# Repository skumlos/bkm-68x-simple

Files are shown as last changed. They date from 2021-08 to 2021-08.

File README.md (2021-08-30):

BKM-68X alternative input board

This project aims to serve as an alternative to the crazy expensive Sony BKM-68X RGB/YPbPr
input card for Sony BVM-A monitors like the BVM-A14F5, A20F1, A24E1W and A32E1W (M/U/A).

The board is rather simple albeit has some components that are not so simple to hand solder,
and it also has a quite high component count (due to a load of resistors and caps).

It's buildup is basically an analog section that deals with video, and a digital section
that speaks to the monitor.

The analog section buffers the video by an THS7374 (with the LPF disabled!) and throws
those through an ADG1611 (or compatible) switch, working via the VIDEO_OE_X signal from
the FPGA. The Y/G signal is first routed through an ISL4089 which strips the sync part 
(if needed) from the signal to avoid too bright picture in YPbPr and SoG signals. This
is however only done if the input is YPbPr at 480p and below and for RGsB signals.
In version 1.1 of the software, this can be switched by turning aperture on. This might
be removed later though, as this is somewhat for testing.

The sync signal is separated through an ISL59885 with a color filter in front (as per
the datasheet), and the signal to be separated (external or Y signal) is chosen via
INT_EXT_X signal to an ADG734 switch.

These are then passed to the FPGA which detects sync polarity and changes accordingly
to positive sync, and then sends the two signals into the monitor.

The digital section consists of a FPGA (Intel MAX 10 in an EQFP-144 package as of this
writing) with a buttload of schmitt triggers and line drivers, all replicated from the
original 68X service manual. The card thus tries to be electrically similar to the
original, at the interface level.

The FPGA is expected to be programmed with the HDL from https://github.com/skumlos/bkm-68x-fpga

75 Ohm termination can be selected by the switches, which either terminates, or passthroughs
(in that case external terminators are needed, unless signal is actually passed through to a
terminating monitor).

The card has no aperture circuit so it can only pass the signal straight through to the monitor
as it originally is (buffered and level conditioned).

Compared to the original BKM-68X, this has severely better sync handling seemingly.

The list of tested consoles that syncs fine as of revision E1 is:

SNES (2CHIP US) 60Hz (CSYNC)

SNES (1CHIP FAT US) 60Hz (CSYNC)

SNES (2CHIP EU) 50Hz (Sync on luma)

SNES (1CHIP EU, SNSP-1CHIP-01) 50Hz (Sync on luma)

Genesis (US) 60Hz (CVBS sync)

Genesis 2 (US) 60Hz (CSYNC)

Mega Drive (EU) 50Hz (CVBS sync)

Mega Drive 2 (EU, DFO) 60Hz (CSYNC)

Mega Drive 2 (EU, DFO) 50Hz (CSYNC)

Master System (on Genesis through Power Base) 60Hz (CVBS sync)

Master System (EU, DFO) 60Hz (CSYNC)

Master System (EU, DFO) 50Hz (CSYNC)

Master System (EU, VA3, no DFO) 60Hz (59,38Hz) (CSYNC)

Master System (EU, VA3, no DFO) 50Hz (CSYNC)

Nintendo 64 (NUSJ) 60Hz (THS7314 RGB) (CSYNC)

Wii (EU) 576i 50Hz (YPbPr)

Wii (EU) 480i 60Hz (YPbPr)

Wii (EU) 480p 60Hz (YPbPr)

PSone SCPH-101 (EU) (MM3+MFO) 60Hz (RGC CSYNC)

PSone SCPH-101 (EU) (MM3+MFO) 50Hz (RGC CSYNC)

PS2 (US) 240p/480i 60Hz (RGBS)

PS2 (US) 480p 60Hz (RGsB)

PS2 (US) 240p/480i/480p (YPbPr)

PS3 (EU) 576i 50Hz (YPbPr)

PS3 (EU) 576p 50Hz (YPbPr)

PS3 (EU) 720p 60Hz (YPbPr)

PS3 (EU) 1080i 60Hz (YPbPr)

PC Engine (White), External RGB mod (THS7374, Genesis 2 plug), 60Hz (CSYNC)

Analogue Nt Mini 2.0 60Hz RGBS (so CSYNC)

Amiga 500 RGBS (PAL) 50Hz (CSYNC)

Xbox 360 (EU) 480i/480p/720p 50/60Hz (YPbPr)

Xbox 360 (EU) 1080i 60Hz (YPbPr) (1080i 50Hz seems to just flicker. Does the same with original 68X)

A load of MiSTer cores which are normally deemed problematic, including DoDonPachi
whose whack VSYNC of 57.6 Hz makes the original BKM-68X scroll the picture with a
steady OSD, while this version has a steady picture with a rolling OSD :)

Master System with CVBS sync works, but sometimes "glitches". This is apparently
due to the quite noisy CVBS signal, which the sync separator picks up. Without
the color filter it is unusable.

It is generally recommended to use CSYNC signals at 75 Ohm levels.

Revision history:

E1: Add "proper" 5V->3.3V translation for sync lines

E: Add "Y/G normalization" control from FPGA

D1: Add STBY_5V pinheader for easier outside-monitor-programming of FPGA.

D: Add DC restore and sync-removal circuit on Y/G line

C1: Minor layout changes

C: Added mounting screw brackets and shortened board for a PCB front, change switch to LFCSP version

B: Added onboard FPGA, color filter, rerouted signals.

A: Initial version

More information @ https://www.immerhax.com

Credits:
Mathias Hyldgaard for providing me with a BVM-A20, which initiated the whole project!
Bob from RetroRGB for testing and listening to my woes :)
The secret benefactor(s) of the original BKM-68X which made the whole project much easier, and ultimately made it possible!
Steve Nutter for being a helpful guy within the pro monitor scene!
The people on the CRT discord and Professional and Broadcast Monitor Facebook group!

(2021) Martin Hejnfelt, martin@hejnfelt.com

This work is released under the CERN Open Hardware Licence version 2 (CERN-OHL-W), see LICENCE.TXT

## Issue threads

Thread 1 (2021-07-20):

Feature Request: Support separate H and V TTL sync inputs

maxtherabbit, 2021-07-20:
This feature would be helpful for the Dreamcast, as well as a myriad of retro computers that output separate sync. Judging by the existing design where all sync sources are separated before being passed along to the monitor, it seems like a fairly trivial feature to accommodate. Amazing work so far!

skumlos, 2021-07-22:
Yes, this should be trivial besides whatever switching mechanism that would also be "needed" and I well definitely put something like this intro this or a future version. I dunno how much it directly helps Dreamcast if the sync from it is whack (as implied by the need of a multivibrator circuit in the vblank period as I understand is present in the RetroAccess cable) but I am gonna look into some of that soon :) and thanks!

maxtherabbit, 2021-07-23:
Well I'm no expert on Dreamcase sync, however I do believe that the use of
the multivibrator in RA's cable is only needed to recreate the serration
pulses during v-blank.

As shown in the attached scope captures, you can see that when natively
outputting separate HV sync, the dreamcast syncs are quite "well-behaved"
with proper h-sync pulses throughout v-blank

On Thu, Jul 22, 2021 at 1:58 PM Martin Hejnfelt ***@***.***>
wrote:

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

maxtherabbit, 2021-07-23:
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

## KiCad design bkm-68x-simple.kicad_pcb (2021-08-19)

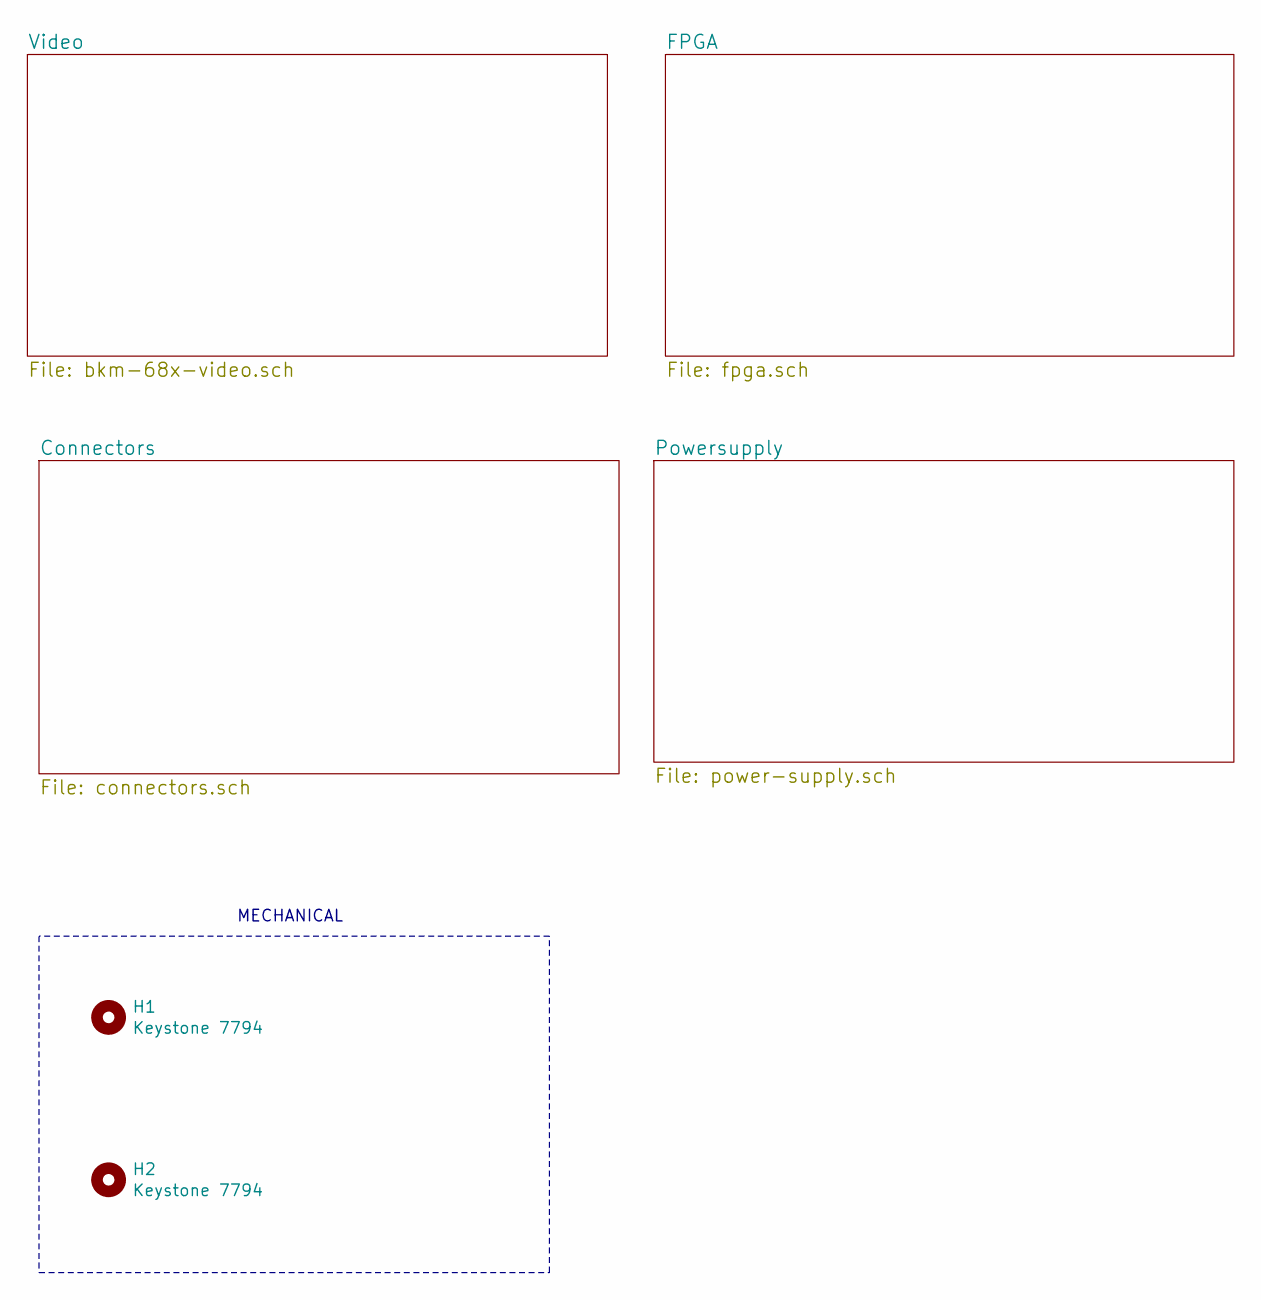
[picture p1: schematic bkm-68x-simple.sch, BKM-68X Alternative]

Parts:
H1, H2: Keystone 7794; 7794-X

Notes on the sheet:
MECHANICAL

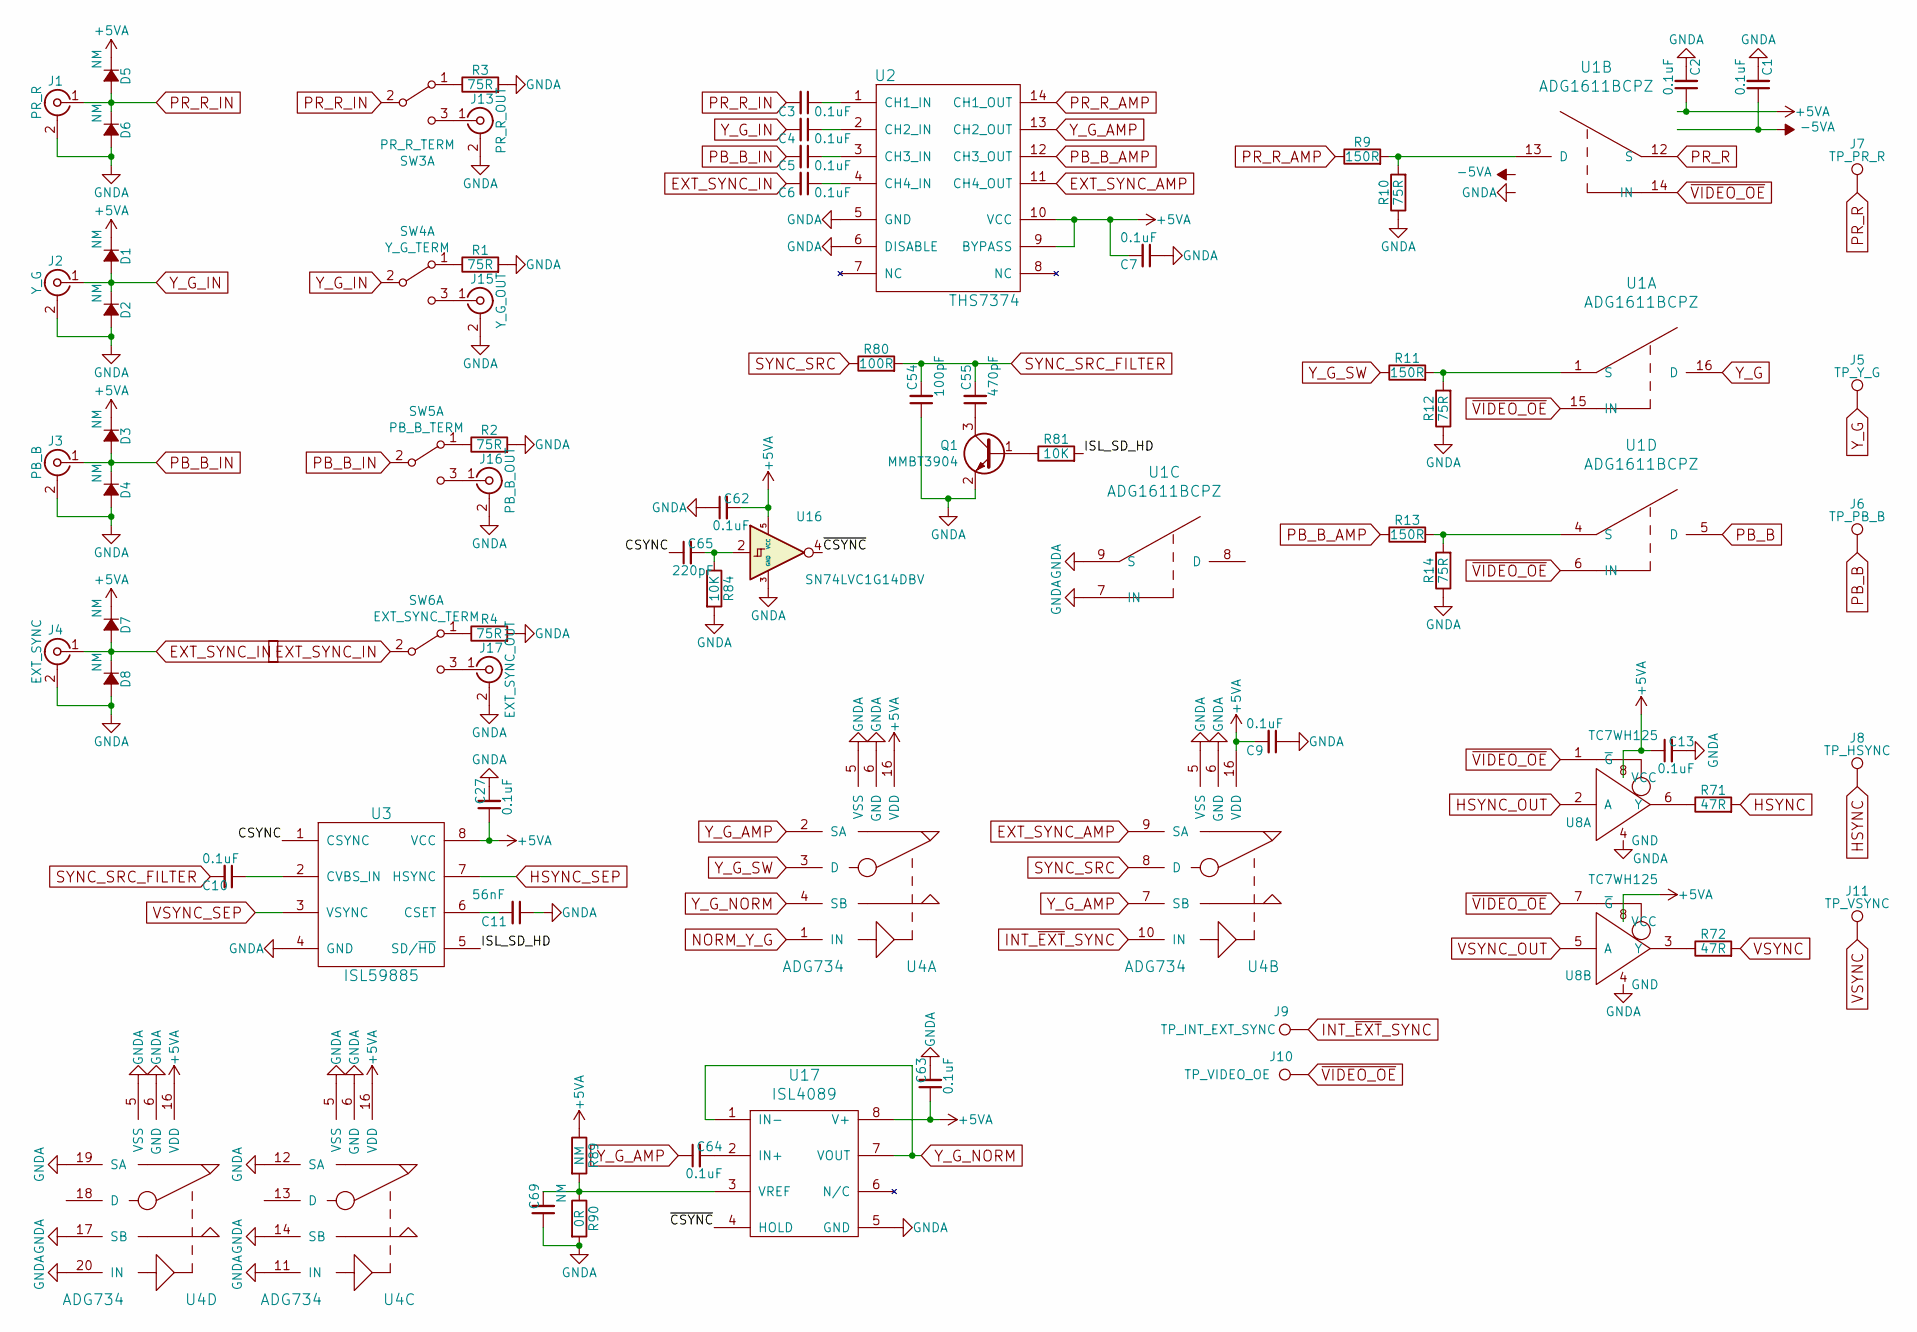
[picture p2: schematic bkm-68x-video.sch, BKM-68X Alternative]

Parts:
C1, C2, C3, C4, C5, C6, C7, C9, C10, C13, C27, C62, C63, C64: 0.1uF; C_0805_2012Metric_Pad1.18x1.45mm_HandSolder
C11: 56nF; C_0805_2012Metric_Pad1.18x1.45mm_HandSolder
C54: 100pF; C_0805_2012Metric_Pad1.18x1.45mm_HandSolder
C55: 470pF; C_0805_2012Metric_Pad1.18x1.45mm_HandSolder
C65: 220pF; C_0805_2012Metric_Pad1.18x1.45mm_HandSolder
C69: NM; C_0805_2012Metric_Pad1.18x1.45mm_HandSolder
D1, D2, D3, D4, D5, D6, D7, D8: NM; D_SOD-123
J1: PR_R; BNC-THT
J2: Y_G; BNC-THT
J3: PB_B; BNC-THT
J4: EXT_SYNC; BNC-THT
J5: TP_Y_G; TestPoint_Pad_D2.0mm
J6: TP_PB_B; TestPoint_Pad_D2.0mm
J7: TP_PR_R; TestPoint_Pad_D2.0mm
J8: TP_HSYNC; TestPoint_Pad_D2.0mm
J9: TP_INT_EXT_SYNC; TestPoint_Pad_D2.0mm
J10: TP_VIDEO_OE; TestPoint_Pad_D2.0mm
J11: TP_VSYNC; TestPoint_Pad_D2.0mm
J13: PR_R_OUT; BNC-THT
J15: Y_G_OUT; BNC-THT
J16: PB_B_OUT; BNC-THT
J17: EXT_SYNC_OUT; BNC-THT
Q1: MMBT3904; SOT-23_Handsoldering
R1, R2, R3, R4, R10, R12, R14: 75R; R_0805_2012Metric_Pad1.20x1.40mm_HandSolder
R9, R11, R13: 150R; R_0805_2012Metric_Pad1.20x1.40mm_HandSolder
R71, R72: 47R; R_0805_2012Metric_Pad1.20x1.40mm_HandSolder
R80: 100R; R_0805_2012Metric_Pad1.20x1.40mm_HandSolder
R81, R84: 10K; R_0805_2012Metric_Pad1.20x1.40mm_HandSolder
R89: NM; R_0805_2012Metric_Pad1.20x1.40mm_HandSolder
R90: 0R; R_0805_2012Metric_Pad1.20x1.40mm_HandSolder
SW3: PR_R_TERM; JS202011SCQN
SW4: Y_G_TERM; JS202011SCQN
SW5: PB_B_TERM; JS202011SCQN
SW6: EXT_SYNC_TERM; JS202011SCQN
U1: ADG1611BCPZ; LFCSP-16-1EP_4x4mm_P0.65mm_EP2.4x2.4mm
U2: THS7374; TSSOP-14_4.4x5mm_P0.65mm
U3: ISL59885; SOIC-8_3.9x4.9mm_P1.27mm
U4: ADG734; TSSOP-20_4.4x6.5mm_P0.65mm
U8: TC7WH125; SSOP-8_2.95x2.8mm_P0.65mm
U16: SN74LVC1G14DBV; SOT-23-5
U17: ISL4089; SOIC-8_3.9x4.9mm_P1.27mm

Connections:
+5VA: C2.1, C7.2, C9.2, C13.1, C27.1, C62.2, C63.1, D1.1 (K), D3.1 (K), D5.1 (K), D7.1 (K), R89.1, U1.11 (VDD), U2.9 (BYPASS), U2.10 (VCC), U3.8 (VCC), U4.16 (VDD), U8.8 (VCC), U16.5 (VCC), U17.8 (V+); also elsewhere on the board
-5VA: C1.1, U1.2 (VSS), U1.17 (EP); also elsewhere on the board
/Video/CSYNC: C65.1, U3.1 (CSYNC)
/Video/ISL_SD_HD: R81.2, U3.5 (SD/~HD)
/Video/~CSYNC: U16.4, U17.4 (HOLD)
EXT_SYNC_AMP: U2.11 (CH4_OUT), U4.9 (SA)
EXT_SYNC_IN: C6.2, D7.2 (A), D8.1 (K), J4.1 (In), SW6.2 (B)
HSYNC: J8.1, R71.2; also elsewhere on the board
HSYNC_OUT: U8.2 (A); also elsewhere on the board
HSYNC_SEP: U3.7 (HSYNC); also elsewhere on the board
INT_~EXT~_SYNC: J9.1, U4.10 (IN); also elsewhere on the board
NORM_Y_G: U4.1 (IN); also elsewhere on the board
unnamed: C3.1, U2.1 (CH1_IN)
unnamed: C4.1, U2.2 (CH2_IN)
unnamed: C5.1, U2.3 (CH3_IN)
unnamed: C6.1, U2.4 (CH4_IN)
unnamed: C10.1, U3.2 (CVBS_IN)
unnamed: C11.2, U3.6 (CSET)
unnamed: C55.1, Q1.3 (C)
unnamed: C64.2, U17.2 (IN+)
unnamed: C65.2, R84.1, U16.2
unnamed: C69.2, R89.2, R90.1, U17.3 (VREF)
unnamed: J13.1 (In), SW3.3 (C)
unnamed: J15.1 (In), SW4.3 (C)
unnamed: J16.1 (In), SW5.3 (C)
unnamed: J17.1 (In), SW6.3 (C)
unnamed: Q1.1 (B), R81.1
unnamed: R1.1, SW4.1 (A)
unnamed: R2.1, SW5.1 (A)
unnamed: R3.1, SW3.1 (A)
unnamed: R4.1, SW6.1 (A)
unnamed: R9.2, R10.2, U1.13 (D)
unnamed: R11.2, R12.2, U1.1 (S)
unnamed: R13.2, R14.2, U1.4 (S)
unnamed: R71.1, U8.6 (Y)
unnamed: R72.1, U8.3 (Y)
PB_B: J6.1, U1.5 (D); also elsewhere on the board
PB_B_AMP: R13.1, U2.12 (CH3_OUT)
PB_B_IN: C5.2, D3.2 (A), D4.1 (K), J3.1 (In), SW5.2 (B)
PR_R: J7.1, U1.12 (S); also elsewhere on the board
PR_R_AMP: R9.1, U2.14 (CH1_OUT)
PR_R_IN: C3.2, D5.2 (A), D6.1 (K), J1.1 (In), SW3.2 (B)
SYNC_SRC: R80.1, U4.8 (D)
SYNC_SRC_FILTER: C10.2, C54.2, C55.2, R80.2
VSYNC: J11.1, R72.2; also elsewhere on the board
VSYNC_OUT: U8.5 (A); also elsewhere on the board
VSYNC_SEP: U3.3 (VSYNC); also elsewhere on the board
Y_G: J5.1, U1.16 (D); also elsewhere on the board
Y_G_AMP: C64.1, U2.13 (CH2_OUT), U4.2 (SA), U4.7 (SB)
Y_G_IN: C4.2, D1.2 (A), D2.1 (K), J2.1 (In), SW4.2 (B)
Y_G_NORM: U4.4 (SB), U17.1 (IN-), U17.7 (VOUT)
Y_G_SW: R11.1, U4.3 (D)
~VIDEO_OE: J10.1, U1.6 (IN), U1.14 (IN), U1.15 (IN), U8.1 (~G), U8.7 (~G); also elsewhere on the board

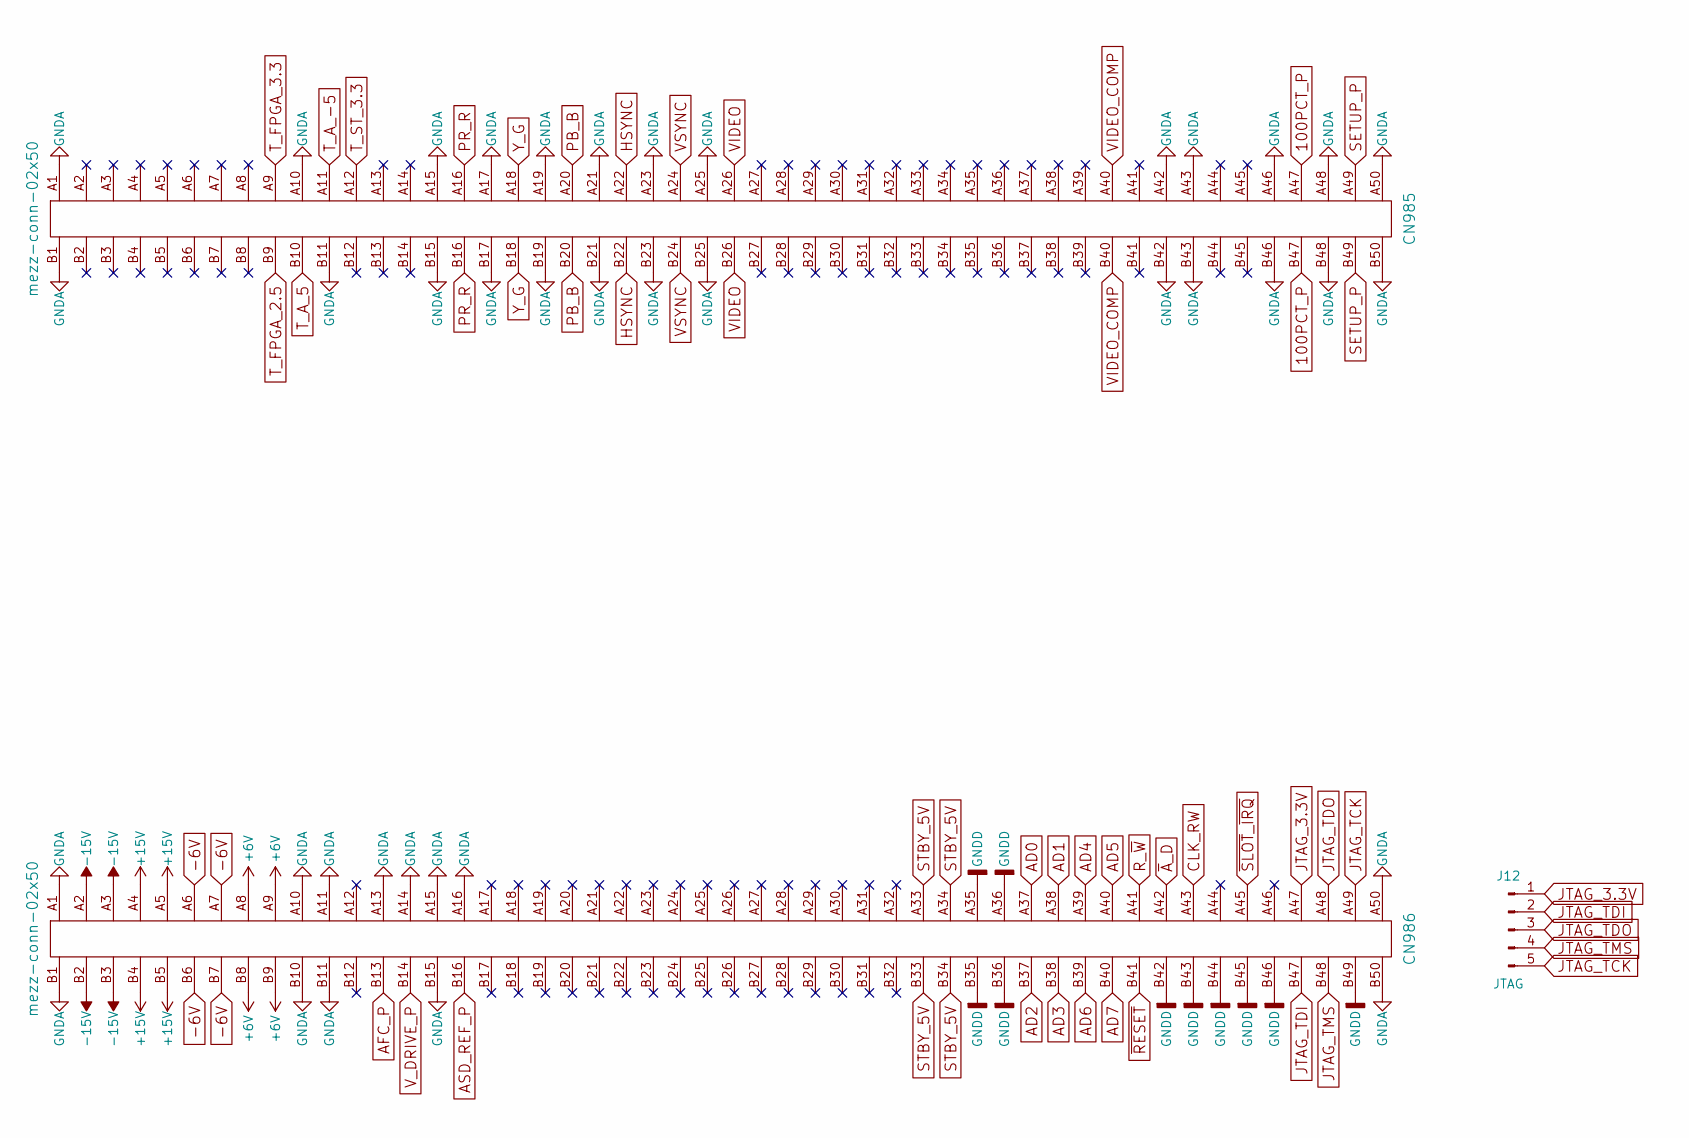
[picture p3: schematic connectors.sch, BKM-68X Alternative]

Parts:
CN985, CN986: mezz-conn-02x50; TX24-100R-LT-H1E
J12: JTAG; PinHeader_1x05_P2.54mm_Vertical

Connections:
100PCT_P: CN985.A47, CN985.B47
+6V: CN986.A8, CN986.A9, CN986.B8, CN986.B9; also elsewhere on the board
+15V: CN986.A4, CN986.A5, CN986.B4, CN986.B5
-6V: CN986.A6, CN986.A7, CN986.B6, CN986.B7; also elsewhere on the board
-15V: CN986.A2, CN986.A3, CN986.B2, CN986.B3
AD0: CN986.A37; also elsewhere on the board
AD1: CN986.A38; also elsewhere on the board
AD2: CN986.B37; also elsewhere on the board
AD3: CN986.B38; also elsewhere on the board
AD4: CN986.A39; also elsewhere on the board
AD5: CN986.A40; also elsewhere on the board
AD6: CN986.B39; also elsewhere on the board
AD7: CN986.B40; also elsewhere on the board
CLK_RW: CN986.A43; also elsewhere on the board
HSYNC: CN985.A22, CN985.B22; also elsewhere on the board
JTAG_3.3V: CN986.A47, J12.1
JTAG_TCK: CN986.A49, J12.5
JTAG_TDI: CN986.B47, J12.2
JTAG_TDO: CN986.A48, J12.3
JTAG_TMS: CN986.B48, J12.4
PB_B: CN985.A20, CN985.B20; also elsewhere on the board
PR_R: CN985.A16, CN985.B16; also elsewhere on the board
R_~W: CN986.A41; also elsewhere on the board
SETUP_P: CN985.A49, CN985.B49
STBY_5V: CN986.A33, CN986.A34, CN986.B33, CN986.B34; also elsewhere on the board
VIDEO: CN985.A26, CN985.B26
VIDEO_COMP: CN985.A40, CN985.B40
VSYNC: CN985.A24, CN985.B24; also elsewhere on the board
Y_G: CN985.A18, CN985.B18; also elsewhere on the board
~A~_D: CN986.A42; also elsewhere on the board
~RESET: CN986.B41; also elsewhere on the board
~SLOT~_~IRQ~: CN986.A45; also elsewhere on the board

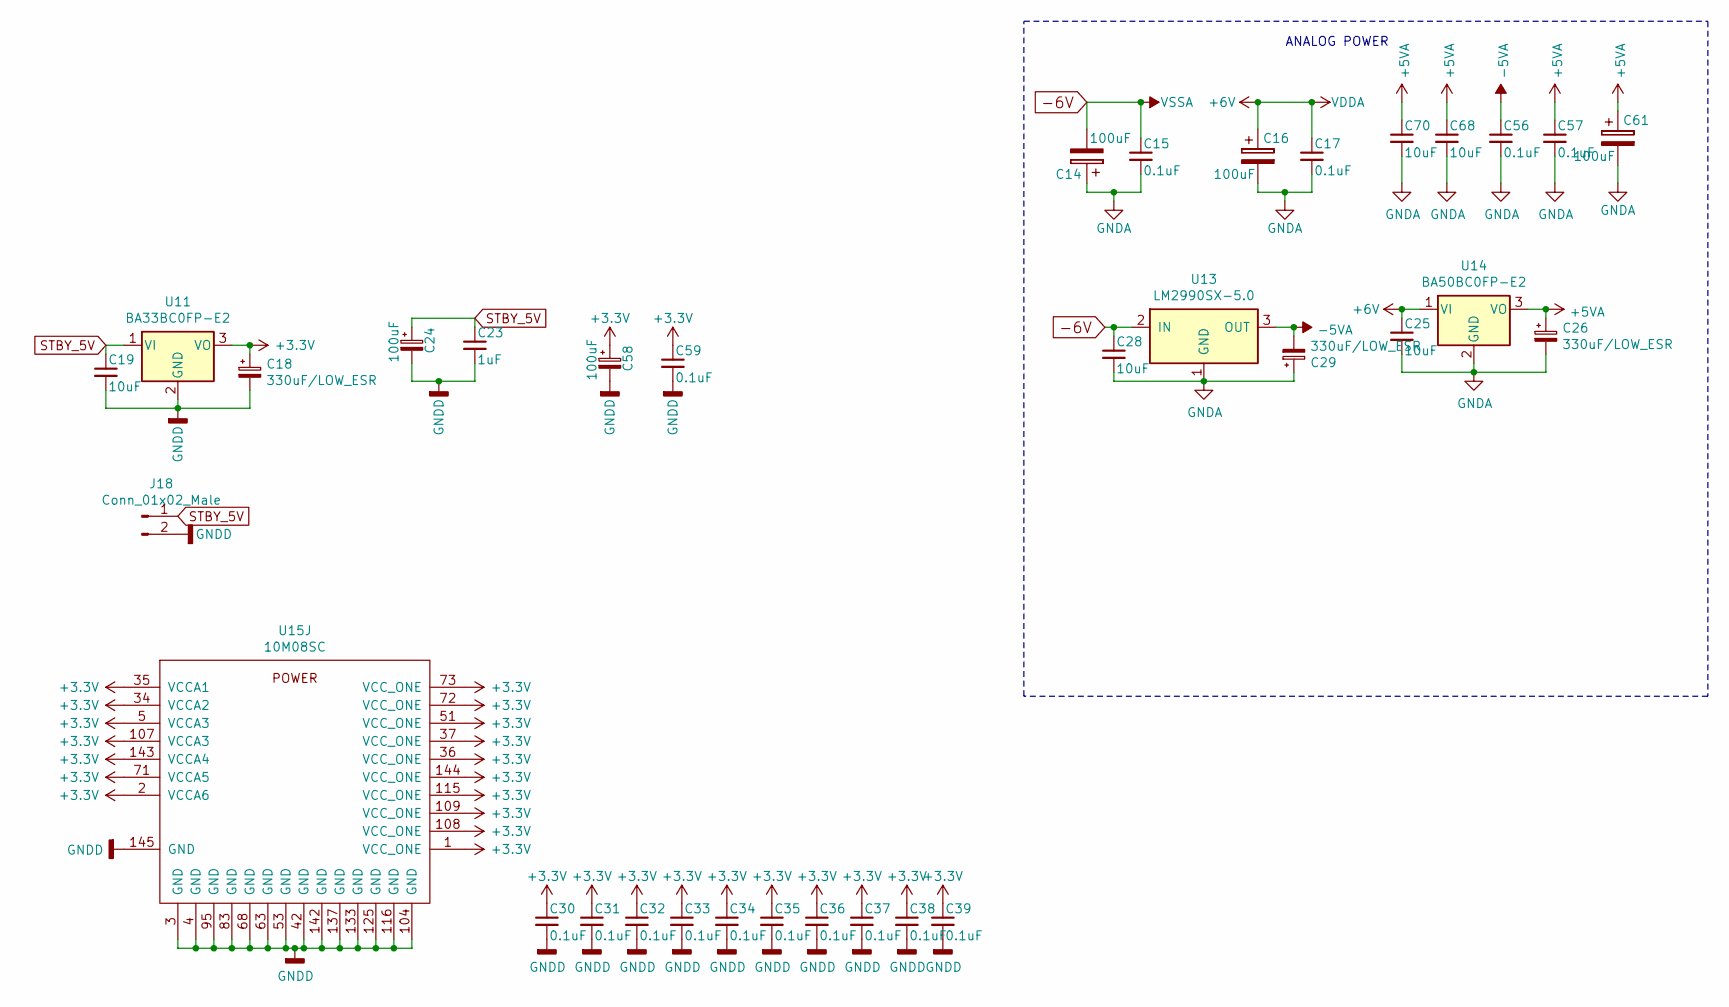
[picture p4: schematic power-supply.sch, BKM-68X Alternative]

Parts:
C14, C16, C61: 100uF; CP_Elec_6.3x5.3
C15, C17, C56, C57, C59: 0.1uF; C_0805_2012Metric_Pad1.18x1.45mm_HandSolder
C18, C26: 330uF/LOW_ESR; CP_Elec_6.3x7.7
C19, C25, C28, C68, C70: 10uF; C_0805_2012Metric_Pad1.18x1.45mm_HandSolder
C23: 1uF; C_0805_2012Metric_Pad1.18x1.45mm_HandSolder
C24, C58: 100uF; CP_Elec_6.3x5.4
C29: 330uF/LOW_ESR; CP_Elec_6.3x5.8
C30, C31, C32, C33, C34, C35, C36, C37, C38, C39: 0.1uF; C_0603_1608Metric_Pad1.08x0.95mm_HandSolder
J18: Conn_01x02_Male; PinHeader_1x02_P2.54mm_Vertical
U11: BA33BC0FP-E2; TO-252-3_TabPin2
U13: LM2990SX-5.0; TO-263-3_TabPin2
U14: BA50BC0FP-E2; TO-252-3_TabPin2
U15: 10M08SC; EQFP-144-1EP_20x20mm_P0.5mm_EP8.93x8.7mm_ThermalVias

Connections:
+3V3: C18.1, C30.1, C31.1, C32.1, C33.1, C34.1, C35.1, C36.1, C37.1, C38.1, C39.1, C58.1, C59.1, U11.3 (VO), U15.1 (VCC_ONE), U15.2 (VCCA6), U15.5 (VCCA3), U15.34 (VCCA2), U15.35 (VCCA1), U15.36 (VCC_ONE), U15.37 (VCC_ONE), U15.51 (VCC_ONE), U15.71 (VCCA5), U15.72 (VCC_ONE), U15.73 (VCC_ONE), U15.107 (VCCA3), U15.108 (VCC_ONE), U15.109 (VCC_ONE), U15.115 (VCC_ONE), U15.143 (VCCA4), U15.144 (VCC_ONE); also elsewhere on the board
+5VA: C26.1, C57.1, C61.1, C68.1, C70.1, U14.3 (VO); also elsewhere on the board
+6V: C16.1, C17.1, C25.1, U14.1 (VI); also elsewhere on the board
-5VA: C29.2, C56.1, U13.3 (OUT); also elsewhere on the board
-6V: C14.2, C15.1, C28.1, U13.2 (IN); also elsewhere on the board
STBY_5V: C19.1, C23.1, C24.1, J18.1, U11.1 (VI); also elsewhere on the board

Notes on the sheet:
ANALOG POWER

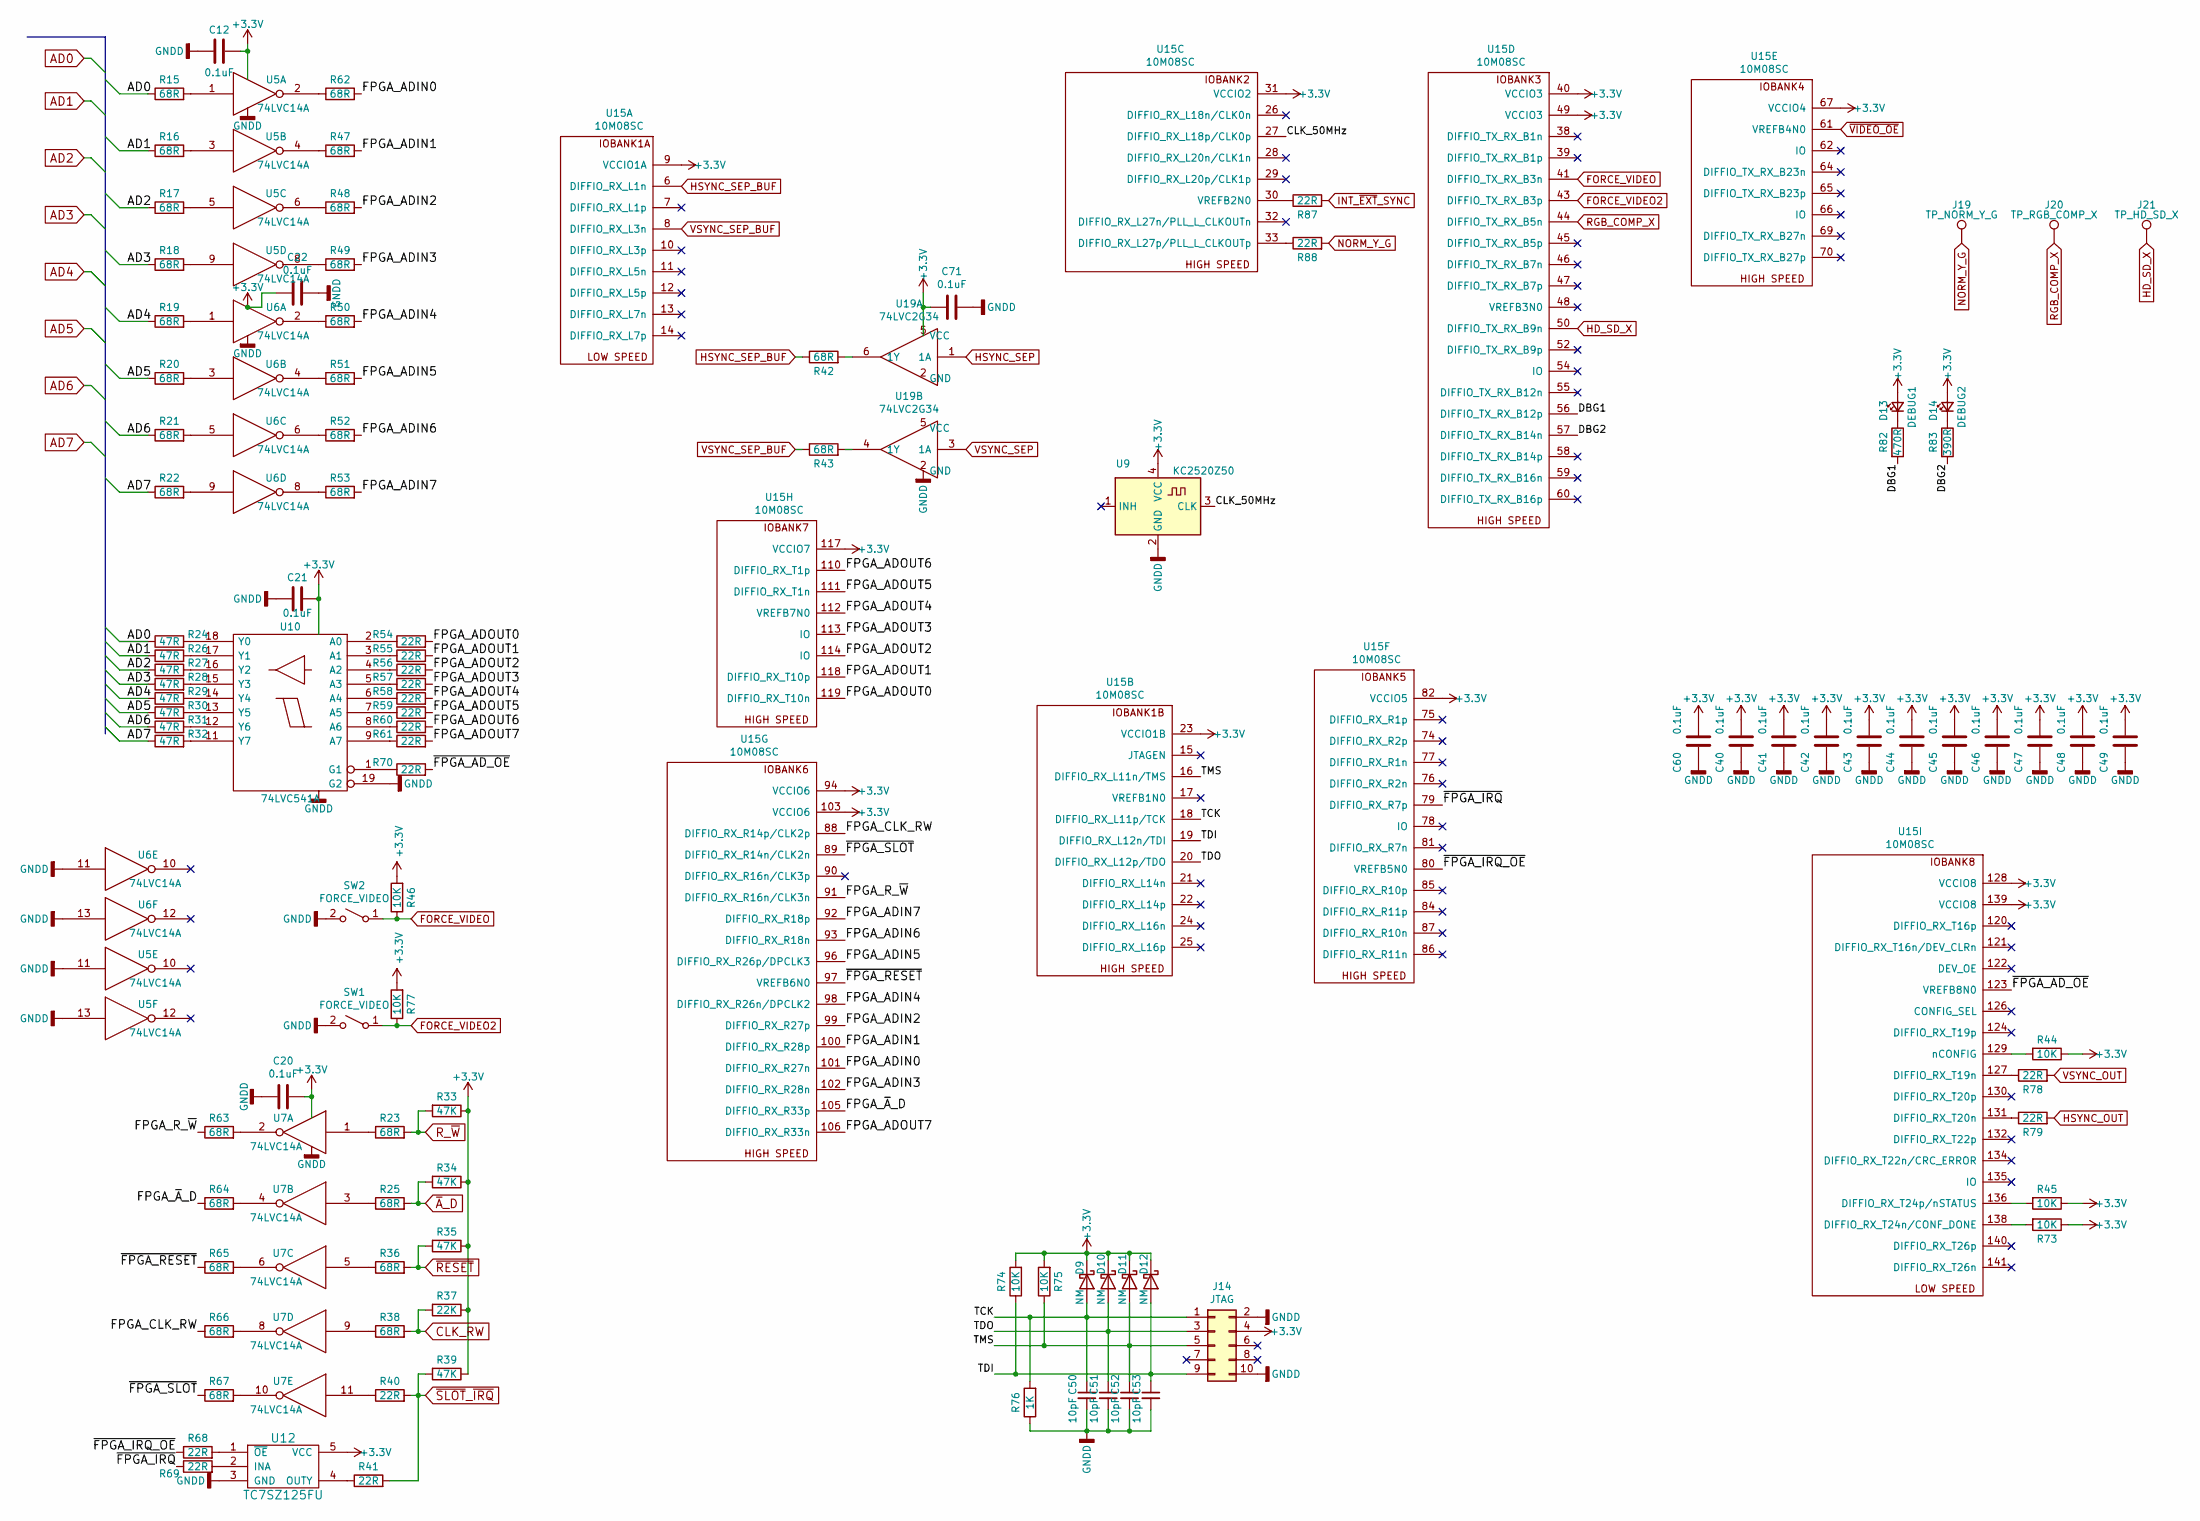
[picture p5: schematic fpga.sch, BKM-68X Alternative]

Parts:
C12, C20, C21, C22, C71: 0.1uF; C_0805_2012Metric_Pad1.18x1.45mm_HandSolder
C40, C41, C42, C43, C44, C45, C46, C47, C48, C49, C60: 0.1uF; C_0603_1608Metric_Pad1.08x0.95mm_HandSolder
C50, C51, C52, C53: 10pF; C_0603_1608Metric_Pad1.08x0.95mm_HandSolder
D9, D10, D11, D12: NM; D_SOD-123
D13: DEBUG1; LED_0805_2012Metric_Pad1.15x1.40mm_HandSolder
D14: DEBUG2; LED_0805_2012Metric_Pad1.15x1.40mm_HandSolder
J14: JTAG; PinHeader_2x05_P2.54mm_Vertical
J19: TP_NORM_Y_G; TestPoint_Pad_D2.0mm
J20: TP_RGB_COMP_X; TestPoint_Pad_D2.0mm
J21: TP_HD_SD_X; TestPoint_Pad_D2.0mm
R15, R16, R17, R18, R19, R20, R21, R22, R23, R25, R36, R38, R42, R43, R47, R48, R49, R50, R51, R52, R53, R62, R63, R64, R65, R66, R67: 68R; R_0805_2012Metric_Pad1.20x1.40mm_HandSolder
R24, R26, R27, R28, R29, R30, R31, R32: 47R; R_0805_2012Metric_Pad1.20x1.40mm_HandSolder
R33, R34, R35, R39: 47K; R_0805_2012Metric_Pad1.20x1.40mm_HandSolder
R37: 22K; R_0805_2012Metric_Pad1.20x1.40mm_HandSolder
R40, R41, R54, R55, R56, R57, R58, R59, R60, R61, R68, R69, R70, R78, R79, R87, R88: 22R; R_0805_2012Metric_Pad1.20x1.40mm_HandSolder
R44, R45, R46, R73, R74, R75, R77: 10K; R_0805_2012Metric_Pad1.20x1.40mm_HandSolder
R76: 1K; R_0805_2012Metric_Pad1.20x1.40mm_HandSolder
R82: 470R; R_0805_2012Metric_Pad1.20x1.40mm_HandSolder
R83: 390R; R_0805_2012Metric_Pad1.20x1.40mm_HandSolder
SW1, SW2: FORCE_VIDEO; PTS645
U5, U6, U7: 74LVC14A; TSSOP-14_4.4x5mm_P0.65mm
U9: KC2520Z50; Oscillator_SMD_Kyocera_KC2520Z-4Pin_2.5x2.0mm
U10: 74LVC541A; TSSOP-20_4.4x6.5mm_P0.65mm
U12: TC7SZ125FU; SOT-353_SC-70-5_Handsoldering
U15: 10M08SC; EQFP-144-1EP_20x20mm_P0.5mm_EP8.93x8.7mm_ThermalVias
U19: 74LVC2G34; SOT-23-6_Handsoldering

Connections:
+3V3: C12.1, C20.1, C21.1, C22.2, C40.1, C41.1, C42.1, C43.1, C44.1, C45.1, C46.1, C47.1, C48.1, C49.1, C60.1, C71.2, D9.1 (K), D10.1 (K), D11.1 (K), D12.1 (K), D13.2 (A), D14.2 (A), J14.4, R33.1, R34.1, R35.1, R37.1, R39.1, R44.1, R45.1, R46.2, R73.1, R74.2, R75.2, R77.2, U5.14 (VCC), U6.14 (VCC), U7.14 (VCC), U9.4 (VCC), U10.20 (VCC), U12.5 (VCC), U15.9 (VCCIO1A), U15.23 (VCCIO1B), U15.31 (VCCIO2), U15.40 (VCCIO3), U15.49 (VCCIO3), U15.67 (VCCIO4), U15.82 (VCCIO5), U15.94 (VCCIO6), U15.103 (VCCIO6), U15.117 (VCCIO7), U15.128 (VCCIO8), U15.139 (VCCIO8), U19.5 (VCC); also elsewhere on the board
/FPGA/CLK_50MHz: U9.3 (CLK), U15.27 (DIFFIO_RX_L18p/CLK0p)
/FPGA/DBG1: R82.2, U15.56 (DIFFIO_TX_RX_B12p)
/FPGA/DBG2: R83.2, U15.57 (DIFFIO_TX_RX_B14n)
/FPGA/FPGA_ADIN0: R62.2, U15.101 (DIFFIO_RX_R27n)
/FPGA/FPGA_ADIN1: R47.2, U15.100 (DIFFIO_RX_R28p)
/FPGA/FPGA_ADIN2: R48.2, U15.99 (DIFFIO_RX_R27p)
/FPGA/FPGA_ADIN3: R49.2, U15.102 (DIFFIO_RX_R28n)
/FPGA/FPGA_ADIN4: R50.2, U15.98 (DIFFIO_RX_R26n/DPCLK2)
/FPGA/FPGA_ADIN5: R51.2, U15.96 (DIFFIO_RX_R26p/DPCLK3)
/FPGA/FPGA_ADIN6: R52.2, U15.93 (DIFFIO_RX_R18n)
/FPGA/FPGA_ADIN7: R53.2, U15.92 (DIFFIO_RX_R18p)
/FPGA/FPGA_ADOUT0: R54.2, U15.119 (DIFFIO_RX_T10n)
/FPGA/FPGA_ADOUT1: R55.2, U15.118 (DIFFIO_RX_T10p)
/FPGA/FPGA_ADOUT2: R56.2, U15.114 (IO)
/FPGA/FPGA_ADOUT3: R57.2, U15.113 (IO)
/FPGA/FPGA_ADOUT4: R58.2, U15.112 (VREFB7N0)
/FPGA/FPGA_ADOUT5: R59.2, U15.111 (DIFFIO_RX_T1n)
/FPGA/FPGA_ADOUT6: R60.2, U15.110 (DIFFIO_RX_T1p)
/FPGA/FPGA_ADOUT7: R61.2, U15.106 (DIFFIO_RX_R33n)
/FPGA/FPGA_CLK_RW: R66.1, U15.88 (DIFFIO_RX_R14p/CLK2p)
/FPGA/FPGA_R_~W: R63.1, U15.91 (DIFFIO_RX_R16n/CLK3n)
/FPGA/FPGA_~A~_D: R64.1, U15.105 (DIFFIO_RX_R33p)
/FPGA/TCK: C50.1, D9.2 (A), J14.1, R76.2, U15.18 (DIFFIO_RX_L11p/TCK)
/FPGA/TDI: C53.1, D12.2 (A), J14.9, R74.1, U15.19 (DIFFIO_RX_L12n/TDI)
/FPGA/TDO: C51.1, D10.2 (A), J14.3, U15.20 (DIFFIO_RX_L12p/TDO)
/FPGA/TMS: C52.1, D11.2 (A), J14.5, R75.1, U15.16 (DIFFIO_RX_L11n/TMS)
/FPGA/~FPGA_AD_OE: R70.2, U15.123 (VREFB8N0)
/FPGA/~FPGA_IRQ: R69.1, U15.79 (DIFFIO_RX_R7p)
/FPGA/~FPGA_IRQ_OE: R68.1, U15.80 (VREFB5N0)
/FPGA/~FPGA_RESET: R65.1, U15.97 (VREFB6N0)
/FPGA/~FPGA_SLOT: R67.1, U15.89 (DIFFIO_RX_R14n/CLK2n)
AD0: R15.1, R24.1; also elsewhere on the board
AD1: R16.1, R26.1; also elsewhere on the board
AD2: R17.1, R27.1; also elsewhere on the board
AD3: R18.1, R28.1; also elsewhere on the board
AD4: R19.1, R29.1; also elsewhere on the board
AD5: R20.1, R30.1; also elsewhere on the board
AD6: R21.1, R31.1; also elsewhere on the board
AD7: R22.1, R32.1; also elsewhere on the board
CLK_RW: R37.2, R38.2; also elsewhere on the board
FORCE_VIDEO: R46.1, SW2.1 (A), U15.41 (DIFFIO_TX_RX_B3n)
FORCE_VIDEO2: R77.1, SW1.1 (A), U15.43 (DIFFIO_TX_RX_B3p)
HD_SD_X: J21.1, U15.50 (DIFFIO_TX_RX_B9n)
HSYNC_OUT: R79.2; also elsewhere on the board
HSYNC_SEP: U19.1 (1A); also elsewhere on the board
HSYNC_SEP_BUF: R42.1, U15.6 (DIFFIO_RX_L1n)
INT_~EXT~_SYNC: R87.2; also elsewhere on the board
NORM_Y_G: J19.1, R88.2; also elsewhere on the board
unnamed: D13.1 (K), R82.1
unnamed: D14.1 (K), R83.1
unnamed: R15.2, U5.1
unnamed: R16.2, U5.3
unnamed: R17.2, U5.5
unnamed: R18.2, U5.9
unnamed: R19.2, U6.1
unnamed: R20.2, U6.3
unnamed: R21.2, U6.5
unnamed: R22.2, U6.9
unnamed: R23.1, U7.1
unnamed: R24.2, U10.18 (Y0)
unnamed: R25.1, U7.3
unnamed: R26.2, U10.17 (Y1)
unnamed: R27.2, U10.16 (Y2)
unnamed: R28.2, U10.15 (Y3)
unnamed: R29.2, U10.14 (Y4)
unnamed: R30.2, U10.13 (Y5)
unnamed: R31.2, U10.12 (Y6)
unnamed: R32.2, U10.11 (Y7)
unnamed: R36.1, U7.5
unnamed: R38.1, U7.9
unnamed: R40.1, U7.11
unnamed: R41.1, U12.4 (OUTY)
unnamed: R42.2, U19.6 (1Y)
unnamed: R43.2, U19.4 (1Y)
unnamed: R44.2, U15.129 (nCONFIG)
unnamed: R45.2, U15.136 (DIFFIO_RX_T24p/nSTATUS)
unnamed: R47.1, U5.4
unnamed: R48.1, U5.6
unnamed: R49.1, U5.8
unnamed: R50.1, U6.2
unnamed: R51.1, U6.4
unnamed: R52.1, U6.6
unnamed: R53.1, U6.8
unnamed: R54.1, U10.2 (A0)
unnamed: R55.1, U10.3 (A1)
unnamed: R56.1, U10.4 (A2)
unnamed: R57.1, U10.5 (A3)
unnamed: R58.1, U10.6 (A4)
unnamed: R59.1, U10.7 (A5)
unnamed: R60.1, U10.8 (A6)
unnamed: R61.1, U10.9 (A7)
unnamed: R62.1, U5.2
unnamed: R63.2, U7.2
unnamed: R64.2, U7.4
unnamed: R65.2, U7.6
unnamed: R66.2, U7.8
unnamed: R67.2, U7.10
unnamed: R68.2, U12.1 (~OE)
unnamed: R69.2, U12.2 (INA)
unnamed: R70.1, U10.1 (G1)
unnamed: R73.2, U15.138 (DIFFIO_RX_T24n/CONF_DONE)
unnamed: R78.1, U15.127 (DIFFIO_RX_T19n)
unnamed: R79.1, U15.131 (DIFFIO_RX_T20n)
unnamed: R87.1, U15.30 (VREFB2N0)
unnamed: R88.1, U15.33 (DIFFIO_RX_L27p/PLL_L_CLKOUTp)
RGB_COMP_X: J20.1, U15.44 (DIFFIO_TX_RX_B5n)
R_~W: R23.2, R33.2; also elsewhere on the board
VSYNC_OUT: R78.2; also elsewhere on the board
VSYNC_SEP: U19.3 (1A); also elsewhere on the board
VSYNC_SEP_BUF: R43.1, U15.8 (DIFFIO_RX_L3n)
~A~_D: R25.2, R34.2; also elsewhere on the board
~RESET: R35.2, R36.2; also elsewhere on the board
~SLOT~_~IRQ~: R39.2, R40.2, R41.2; also elsewhere on the board
~VIDEO_OE: U15.61 (VREFB4N0); also elsewhere on the board

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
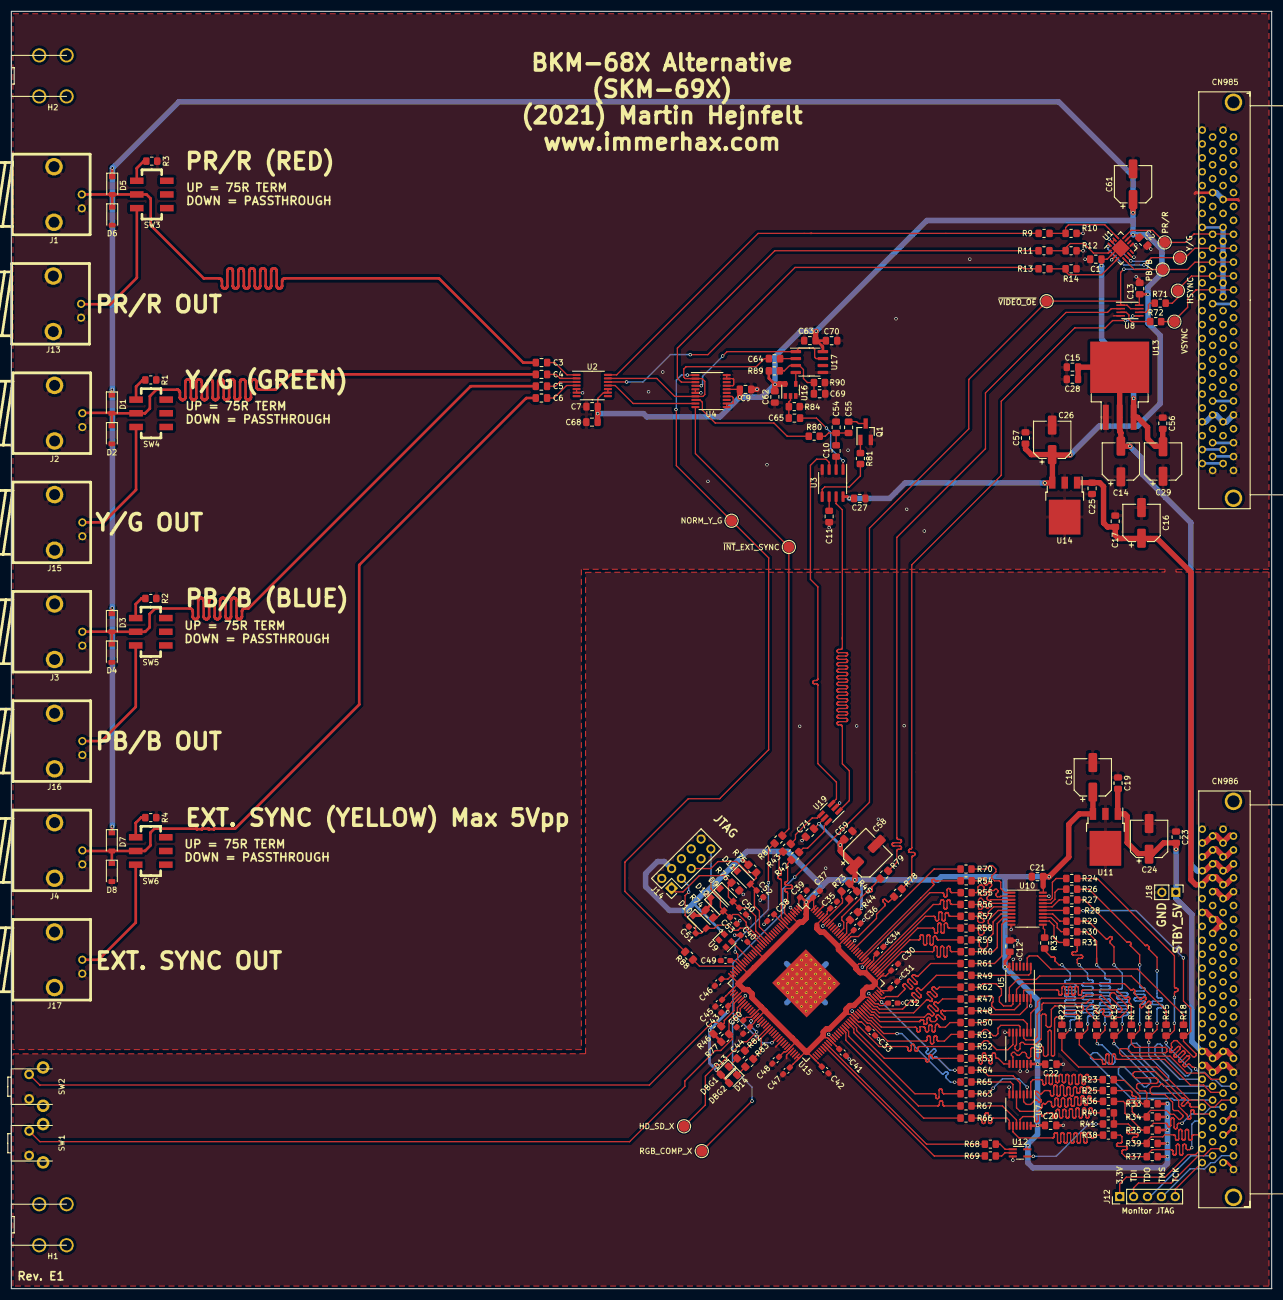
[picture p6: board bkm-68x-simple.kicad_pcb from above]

Board: 2 copper layers, 230.4 x 233.5 mm, 216 parts (0 on the bottom side), 176 nets.

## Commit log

2021-03-21 Minor fixes and cleanups
    [bkm-68x-simple.kicad_pcb, power-supply.sch]
2021-04-18 A lotta fixes
    [bkm-68x-simple.kicad_pcb, bkm-68x-video.sch, fpga.sch]
2021-05-14 Onboard FPGA, passthroughs and a lot of other stuff
    [bkm-68x-simple.kicad_pcb, bkm-68x-video.sch, fpga.sch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]
2021-05-16 Updated some component values
    [bkm-68x-simple.kicad_pcb, bkm-68x-video.sch, fpga.sch]
2021-05-16 Fixes and additions
    [bkm-68x-simple.kicad_pcb, bkm-68x-simple.sch, fpga.sch]
2021-05-17 Shortened board slightly for PCB front, rev C
    [bkm-68x-simple.kicad_pcb]
2021-05-25 Replace ADG1611BRUZ with BCPZ
    Should also be compatible with Vishay DG1411EEN-T1-GE4
    [bkm-68x-simple.kicad_pcb, bkm-68x-video.sch, power-supply.sch]
2021-06-01 Rev C1
    [bkm-68x-simple.kicad_pcb, bkm-68x-video.sch, power-supply.sch]
2021-06-01 Add Rev C1 plot
    [bkm-68x-simple-B_Cu.gbr, bkm-68x-simple-B_Mask.gbr, bkm-68x-simple-B_SilkS.gbr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]
2021-07-01 Name screw mount part, add licence
    [bkm-68x-simple.sch]
2021-07-15 Revision D
    [bkm-68x-simple-B_Cu.gbr, bkm-68x-simple-B_Mask.gbr, bkm-68x-simple-B_SilkS.gbr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]
2021-07-17 Revision D1
    [bkm-68x-simple-B_Cu.gbr, bkm-68x-simple-B_Mask.gbr, bkm-68x-simple-B_SilkS.gbr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]
2021-08-19 Rev. E
    [bkm-68x-simple-B_Cu.gbr, bkm-68x-simple-B_Mask.gbr, bkm-68x-simple-B_SilkS.gbr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]
2021-08-19 Rev. E1
    [bkm-68x-simple-B_Cu.gbr, bkm-68x-simple-B_Mask.gbr, bkm-68x-simple-B_SilkS.gbr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]
2021-08-30 Updated plots
    [bkm-68x-simple-B_Cu.gbr, bkm-68x-simple-B_Mask.gbr, bkm-68x-simple-B_SilkS.gbr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]
